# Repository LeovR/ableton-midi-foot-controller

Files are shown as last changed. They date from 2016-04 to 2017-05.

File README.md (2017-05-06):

# AMTraC - Ableton Midi fooT Controller
MIDI foot controller for Ableton

Use in combination with [AMTraC-Info](https://github.com/LeovR/amtrac-info)

## Introduction
For a band project of mine we wanted to extend our sound with samples. Therefore, I needed the possibility to start songs by foot. In addition, I wanted to have the opportunity to stop songs, repeat a part of a song, check the tempo, and see which part the song is currently in.

To add samples to your sound, in a live setup, the software which usually is used is [Ableton Live](http://www.ableton.com).
Ableton Live let's you trigger a lot of things via MIDI, which covers a lot of things I wanted to have.
There are a lot of MIDI foot controllers out there which could be used for such a setup. But none of these covered all my needs for such a controller. Thus, I decided to build my own MIDI controller.

## Hardware

### Controller
For the controller I decided to use the [Teensy 3.2](https://www.pjrc.com/store/teensy32.html) controller which is Arduino compatible, has 34 Digital I/O pins and natively supports MIDI. Thus, it is quite easy to use MIDI.

### Case
For the controller I wanted to have 2 have an LCD, to display the current song / part, 1 stop-Button, 1 play/repeat-Button, 2 bank-switch-buttons and 6 buttons to select a song. Each button should have a corresponding LED and I wanted to have an additional LED which corresponds to the click of the song.
Thus, in total I needed a quite large case to fit everything on it.

After some googling I decided to use the **Hammond 1441-14** case.

I used simple LEDs and foot buttons.

## LCD
As the LCD I used a **Blue IIC 16x2 LCD** which should have enough space to display the required information.

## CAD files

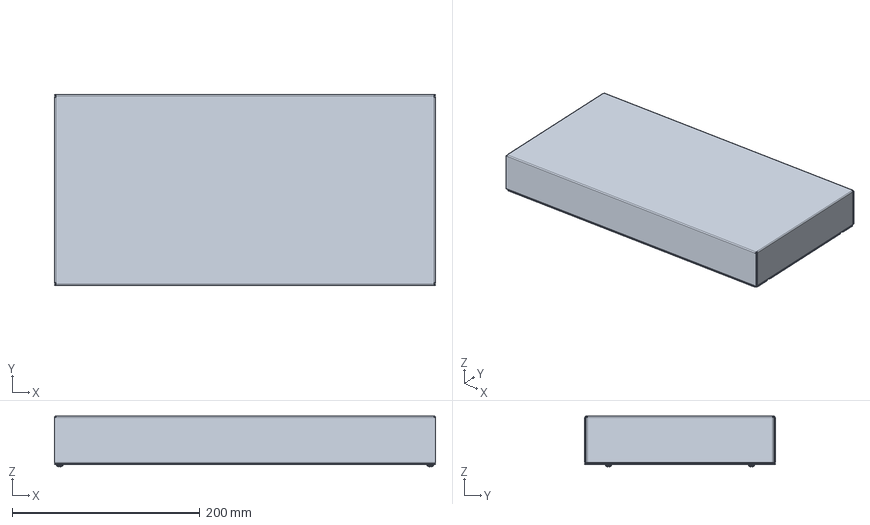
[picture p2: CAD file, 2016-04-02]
gehaeuse.fcstd
406.4 x 203.2 x 54.2 mm
_441_26___Assembly
_441_26___Assembly001
_441_26___Assembly002
_441_26___Assembly003
_441_26___Assembly004
_441_26___Assembly005

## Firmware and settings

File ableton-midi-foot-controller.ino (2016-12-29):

#include "Button.h"
#include "base64/Base64.h"
#include <Wire.h>
#include "NewLiquidCrystal/LiquidCrystal_I2C.h"

//#define DEBUG_BUTTONS true
//#define SINGLE_LED_TEST true
//#define LCD_TEST true
//#define SONG_CONFIGURATION_DEBUG true
//#define DEBUG_BANK true

byte counter;
byte tempCounter;
const byte CLOCK = 248;
const byte START = 250;
const byte CONTINUE = 251;
const byte STOP = 252;

#define SYSEX_BUFFER_SIZE 100
char sysexBuffer[SYSEX_BUFFER_SIZE];

#define MAX_ROW_LENGTH 16

char partBuffer[MAX_ROW_LENGTH + 1];

// LEDs
const byte ledPin = 13;
const byte bpmLed = 17;
const byte ledPins[] = {10, 11, 12, 14, 15, 16};
const byte bankDownLed = 22;
const byte bankUpLed = 23;
const byte playLed = 20;
const byte stopLed = 21;

const byte allLeds[] = {ledPin, bpmLed, ledPins[0], ledPins[1], ledPins[2],
                        ledPins[3], ledPins[4], ledPins[5], bankDownLed, bankUpLed, playLed, stopLed
                       };

const byte numberOfLeds = 12;

// LCD
LiquidCrystal_I2C lcd(0x3F, 2, 1, 0, 4, 5, 6, 7, 3, POSITIVE);

// Buttons
const byte channelButtonStart = 0;
const byte numberOfChannelButtons = 6;
const byte numberOfAllButtons = 10;

const byte bankDownPin = 6;
const byte bankUpPin = 7;

const byte stopPin = 8;
const byte playPin = 9;

Button channelButtons[numberOfChannelButtons];

Button bankDownButton = Button();
Button bankUpButton = Button();
boolean bankDownState;
boolean bankDownDown;
boolean bankUpState;
boolean bankUpDown;

Button stopButton = Button();
Button playButton = Button();
boolean stopState;
boolean stopDown;
boolean playState;
boolean playDown;

Button* allButtons[numberOfChannelButtons + 4];

boolean bankDownLastState = false;
boolean bankUpLastState = false;

byte bank = 0;

const byte numberOfBanks = 5;

const byte numberOfPadBanks = 2;

// Modes
const byte UNCONFIGURED = 0;
const byte NORMAL_MODE = 1;
const byte INIT_MODE = 2;
const byte SONG_MODE = 3;
const byte modeCount = 4;
byte mode = UNCONFIGURED;

byte initBank = 0;

const char mode_0[] PROGMEM = "Normal-Mode";
const char mode_1[] PROGMEM = "Init-Mode";
const char* const modeNames[] PROGMEM = {mode_0, mode_1};

const char displayName[] PROGMEM = "AMTraC";

boolean bothBanksDown = false;

const byte midiChannel = 1;

const byte SONG_CONFIGURATION = 0;
const byte CONFIGURATION_START = 1;
const byte CONFIGURATION_FINISHED = 2;
const byte CURRENT_PART = 3;
const byte NEXT_PART = 4;
const byte SONG_SIGNATURE = 5;
const byte METRONOME = 6;
const byte PAD_CONFIGURATION = 7;

const byte SONG_OFFSET = 10;

const byte numberOfSongs = 30;
char songs[numberOfSongs][MAX_ROW_LENGTH + 1];

const byte CONTROL_OFFSET = SONG_OFFSET + numberOfSongs + 1;

const byte numberOfControls = 10;

const byte STOP_MIDI_NOTE = 0;
const byte REPEAT_MIDI_NOTE = CONTROL_OFFSET;
const byte SEND_CONFIGURATION = CONTROL_OFFSET + 1;
const byte STOP_CLIPS = CONTROL_OFFSET + 2;
const byte METRONOME_MIDI_NOTE = CONTROL_OFFSET + 3;

const byte PAD_OFFSET = CONTROL_OFFSET + numberOfControls + 1;
const byte numberOfPads = 12;
char pads[numberOfPads][MAX_ROW_LENGTH + 1];

byte selectedSong = -1;
byte selectedPad = -1;
const byte INVALID_MIDI_NOTE = 254;
byte midiNoteToSend = INVALID_MIDI_NOTE;
elapsedMillis midiNoteSendStart = 0;
boolean startedMidiNoteSending = false;

boolean playing = false;
byte numerator;
byte denominator;
byte bars;
double fullDenominator;

byte currentNumerator = 0;

boolean nextPartScheduled = false;

boolean repeat = false;
elapsedMillis repeatElapsed = 0;

elapsedMillis triggeredElapsed = 0;
boolean metronomeOn = false;

void OnNoteOn(byte channel, byte note, byte velocity) {
  digitalWrite(ledPin, HIGH);
}

void OnNoteOff(byte channel, byte note, byte velocity) {
  digitalWrite(ledPin, LOW);
}

void SystemExclusiveMessage(const unsigned char *array, short unsigned int size, bool sysexbool) {
  unsigned char *dataArray = (unsigned char*)(array + 4);
  unsigned int realSize = size - 5;

  int decodedLen = base64_dec_len((char*)dataArray, realSize);
  char decoded[decodedLen];

  base64_decode(decoded, (char*)dataArray, realSize);

  boolean isConfigurationMessage = strchr(decoded, '{') != NULL;

  if (isConfigurationMessage) {
    byte configurationType = getConfigurationType(decoded + 1);
    switch (configurationType) {
      case SONG_CONFIGURATION:
        handleSongConfiguration(decoded + 4);
        break;
      case CONFIGURATION_START:
        handleConfigurationStart();
        break;
      case CONFIGURATION_FINISHED:
        handleConfigurationFinished();
        break;
      case CURRENT_PART:
        handleCurrentPart(decoded + 4);
        break;
      case NEXT_PART:
        handleNextPart(decoded + 4);
        break;
      case SONG_SIGNATURE:
        handleSongSignature(decoded + 4);
        break;
      case METRONOME:
        handleMetronome(decoded + 3);
        break;
      case PAD_CONFIGURATION:
        handlePadConfiguration(decoded + 4);
        break;
    }
  }
}

void handleCurrentPart(char* message) {
  if (mode != SONG_MODE) {
    return;
  }

  copyToDisplayBuffer(partBuffer, message);

  nextPartScheduled = false;
  bars = 0;

  lcd.clear();
  lcd.setCursor(0, 0);
  lcd.print(partBuffer);
}

void handleSongSignature(char* messageOriginal) {
  if (mode != SONG_MODE) {
    return;
  }
  sysexBuffer[0] = (char)0;

  strcpy(sysexBuffer, messageOriginal);
  char* strings;
  strings = strtok(sysexBuffer, "|");
  if (strings == NULL) {
    return;
  }

  byte numeratorTemp = atoi(strings);

  strings = strtok(NULL, "|");
  if (strings == NULL) {
    return;
  }

  byte denominatorTemp = atoi(strings);
  numerator = numeratorTemp;
  denominator = denominatorTemp;

}

void clearLine(byte line) {
  lcd.setCursor(0, line);
  lcd.print(F("                "));
}

void handleNextPart(char* message) {
  if (mode != SONG_MODE) {
    return;
  }

  copyToDisplayBuffer(partBuffer, message);

  nextPartScheduled = true;
  triggeredElapsed = 0;

  clearLine(1);
  lcd.setCursor(0, 1);
  lcd.print(partBuffer);
}

void handleMetronome(char* message) {
  metronomeOn = strcmp(message, "1") == 0;
}

void copyToDisplayBuffer(char* displayBuffer, char* message) {
  displayBuffer[0] = (char)0;

  strncpy(displayBuffer, message, MAX_ROW_LENGTH);
  byte messageLength = strlen(message);
  if (messageLength < MAX_ROW_LENGTH) {
    displayBuffer[messageLength] = (char)0;
  } else {
    displayBuffer[MAX_ROW_LENGTH] = (char)0;
  }
}

void handleConfigurationStart() {
  lcd.clear();
  lcd.print(F("Configuration"));
  lcd.setCursor(0, 1);
  lcd.print(F("start"));
}

void handleConfigurationFinished() {
#ifdef SONG_CONFIGURATION_DEBUG
  for (byte i = 0; i < numberOfSongs; i++) {
    if (songs[i]) {
      Serial.print(i);
      Serial.print(F(" "));
      Serial.println(songs[i]);
    }
  }
#endif
  lcd.clear();
  lcd.print(F("Configuration"));
  lcd.setCursor(0, 1);
  lcd.print(F("finished"));

  allLedsTest();
  lcd.clear();

  selectedSong = 0;
  selectedPad = 0;
  changeMode(NORMAL_MODE);
}

void handleSongConfiguration(char* messageOriginal) {
  sysexBuffer[0] = (char)0;
  strcpy(sysexBuffer, messageOriginal);
  char* strings;
  strings = strtok(sysexBuffer, "|");
  if (strings == NULL) {
    return;
  }

  byte index = atoi(strings);

  strings = strtok(NULL, "|");
  if (strings == NULL) {
    return;
  }

#ifdef SONG_CONFIGURATION_DEBUG
  Serial.print(F("Received song configuration "));
  Serial.print(index);
  Serial.print(F(" "));
  Serial.println(strings);
#endif

  copyToDisplayBuffer(songs[index], strings);
}


void handlePadConfiguration(char* messageOriginal) {
  sysexBuffer[0] = (char)0;
  strcpy(sysexBuffer, messageOriginal);
  char* strings;
  strings = strtok(sysexBuffer, "|");
  if (strings == NULL) {
    return;
  }

  byte index = atoi(strings);

  strings = strtok(NULL, "|");
  if (strings == NULL) {
    return;
  }

  copyToDisplayBuffer(pads[index], strings);
}

byte getConfigurationType(char* messageOriginal) {
  strcpy(sysexBuffer, messageOriginal);
  char* strings;
  strings = strtok(sysexBuffer, "|");
  if (strings == NULL) {
    return -1;
  }
  if (strcmp(strings , "SC") == 0) {
    return SONG_CONFIGURATION;
  } else if (strcmp(strings , "CS") == 0) {
    return CONFIGURATION_START;
  } else if (strcmp(strings , "CF") == 0) {
    return CONFIGURATION_FINISHED;
  } else if (strcmp(strings, "CP") == 0) {
    return CURRENT_PART;
  } else if (strcmp(strings, "NP") == 0) {
    return NEXT_PART;
  } else if (strcmp(strings, "SS") == 0) {
    return SONG_SIGNATURE;
  } else if (strcmp(strings, "M") == 0) {
    return METRONOME;
  } else if (strcmp(strings, "PC") == 0) {
    return PAD_CONFIGURATION;
  }
  return -1;
}

void setupButtons() {
  for (byte i = 0; i < numberOfChannelButtons; i++) {
    channelButtons[i].init(channelButtonStart + i, ledPins[i]);
    allButtons[i] = &channelButtons[i];
  }
  bankDownButton.init(bankDownPin, bankDownLed);
  allButtons[numberOfChannelButtons + 0] = &bankDownButton;
  bankUpButton.init(bankUpPin, bankUpLed);
  allButtons[numberOfChannelButtons + 1] = &bankUpButton;
  stopButton.init(stopPin, stopLed);
  allButtons[numberOfChannelButtons + 2] = &stopButton;
  playButton.init(playPin, playLed);
  allButtons[numberOfChannelButtons + 3] = &playButton;
}

void setupLeds() {
  pinMode(ledPin, OUTPUT);
  pinMode(bpmLed, OUTPUT);
}


void setup()
{
  setupButtons();
  setupLeds();

  Serial.begin(9600);

  setupLcd();

  usbMIDI.setHandleNoteOff(OnNoteOff);
  usbMIDI.setHandleNoteOn(OnNoteOn);
  usbMIDI.setHandleRealTimeSystem(RealTimeSystem);
  usbMIDI.setHandleSysEx(SystemExclusiveMessage);

#ifdef LCD_TEST
  lcdTest();
#endif
#ifdef SINGLE_LED_TEST
  ledTest();
#endif

  lcd.clear();
  lcd.setCursor(0, 0);
  lcd.print(displayName);
  allLedsTest();

  delay(3000);

  midiNoteSendStart = 0;
  midiNoteToSend = SEND_CONFIGURATION;
}

#ifdef LCD_TEST
void lcdTest() {
  for (int i = 0; i < 3; i++) {
    lcd.backlight();
    delay(250);
    lcd.noBacklight();
    delay(250);
  }
  lcd.backlight();
}
#endif

void setupLcd() {
  lcd.begin(16, 2);
  lcd.backlight();
}

#ifdef SINGLE_LED_TEST
void ledTest() {
  ledTest(ledPin);
  ledTest(bpmLed);
  for (byte i = 0; i < numberOfChannelButtons; i++) {
    ledTest(ledPins[i]);
  }
  ledTest(bankDownLed);
  ledTest(bankUpLed);
  ledTest(stopLed);
  ledTest(playLed);
}
#endif

void allLedsTest() {
  for (int i = 0; i < numberOfLeds; i++) {
    digitalWrite(allLeds[i], HIGH);
  }
  delay(1000);
  for (int i = 0; i < numberOfLeds; i++) {
    digitalWrite(allLeds[i], LOW);
  }
}

void ledTest(byte pin) {
  digitalWrite(pin, HIGH);
  delay(150);
  digitalWrite(pin, LOW);
  delay(150);
}

void debugButton(Button *button) {
#ifdef DEBUG_BUTTONS
  Serial.print(F("Button: "));
  Serial.print((*button).getPin());
  Serial.print(F(" Just pressed: "));
  Serial.print((*button).isJustPressed());
  Serial.print(F(" Pressed: "));
  Serial.print((*button).isPressed());
  Serial.print(F(" Just released : "));
  Serial.println((*button).isJustReleased());
#endif
}

void updateButtons() {
  for (byte i = 0; i < numberOfAllButtons; i++) {
    if ((*allButtons[i]).update()) {
      debugButton(allButtons[i]);
    }
  }
}

void sendInitMidiNotes() {
  for (byte i = 0; i < numberOfChannelButtons; i++) {
    if (channelButtons[i].isJustReleased()) {
      usbMIDI.sendNoteOff(i + (initBank * numberOfChannelButtons), 0, midiChannel);
    } else if (channelButtons[i].isJustPressed()) {
      usbMIDI.sendNoteOn(i + (initBank * numberOfChannelButtons), 99, midiChannel);
      Serial.print(F("Midi-Note "));
      Serial.println(i + (initBank * numberOfChannelButtons));
    }
  }
}


void sendMidiNote() {
  if (midiNoteToSend != INVALID_MIDI_NOTE) {
    if (midiNoteSendStart > 100) {
      usbMIDI.sendNoteOff(midiNoteToSend, 0, midiChannel);
      midiNoteToSend = INVALID_MIDI_NOTE;
      startedMidiNoteSending = false;
    } else if (!startedMidiNoteSending) {
      usbMIDI.sendNoteOn(midiNoteToSend, 99, midiChannel);
      startedMidiNoteSending = true;
    }
  }
}

void loop()
{
  usbMIDI.read();

  updateButtons();

  boolean modeChange = changeMode();
  if (modeChange) {
    if (mode == NORMAL_MODE && playing) {
      mode = SONG_MODE;
    } else if (mode == SONG_MODE) {
      mode = NORMAL_MODE;
      turnAllChannelButtonsOff();
      resetBankLeds();
      turnCurrentSelectionLedOn();
      printCurrentSelection();
    }
    return;
  }

  if (bothBanksDown) {
    return;
  }

  switch (mode) {
    case NORMAL_MODE:
      handleNormalMode();
      break;
    case INIT_MODE:
      handleInitMode();
      break;
    case SONG_MODE:
      handleSongMode();
      break;
    case UNCONFIGURED:
      handleUnconfigured();
      break;
  }
}

void handleUnconfigured() {
  sendMidiNote();
}

void turnCurrentSelectionLedOn() {
  if (bank < numberOfBanks) {
    turnCurrentSongLedOn();
  } else {
    turnCurrentPadLedOn();
  }
}

void printCurrentSelection() {
  if (bank < numberOfBanks) {
    printCurrentSong();
  } else {
    printCurrentPad();
  }
}

void handleSongMode() {
  if (!repeat) {
    if (playing) {
      playButton.turnLedOn();
    } else {
      playButton.turnLedOff();
    }
  }

  if (metronomeOn) {
    bankDownButton.turnLedOn();
  } else {
    bankDownButton.turnLedOff();
  }

  if (bankDownButton.isJustReleased()) {
    midiNoteSendStart = 0;
    midiNoteToSend = METRONOME_MIDI_NOTE;
  }


  if (stopButton.isJustPressed()) {
    stopButton.turnLedOn();
  }

  if (stopButton.isJustReleased()) {
    midiNoteSendStart = 0;
    midiNoteToSend = STOP_MIDI_NOTE;
    bars = 0;
    nextPartScheduled = false;
    changeMode(NORMAL_MODE);
    return;
  }

  if (playButton.isJustReleased()) {
    repeat = !repeat;
    repeatElapsed = 0;
    midiNoteSendStart = 0;
    midiNoteToSend = REPEAT_MIDI_NOTE;
  }

  if (repeat && repeatElapsed > 300) {
    if (playButton.isLedTurnedOn()) {
      playButton.turnLedOff();
    } else {
      playButton.turnLedOn();
    }
    repeatElapsed = 0;
  }

  if (!nextPartScheduled) {
    bankUpButton.turnLedOff();
  }

  if (triggeredElapsed > 200 && nextPartScheduled) {
    if (bankUpButton.isLedTurnedOn()) {
      bankUpButton.turnLedOff();
    } else {
      bankUpButton.turnLedOn();
    }
    triggeredElapsed = 0;
  }

  sendMidiNote();
}

void changeMode(byte newMode) {
  mode = newMode;
  resetLeds();
  if (mode == NORMAL_MODE) {
    handleNormalMode(true);
  }
}

void handleInitMode() {
  changeInitMidiBank();
  sendInitMidiNotes();
  updateInitLeds();
}

void changeInitMidiBank() {
  boolean update = false;
  if (bankDownButton.isJustReleased()) {
    initBank--;
    if (initBank == 255) {
      initBank = 126;
    }
    update = true;
  } else if (bankUpButton.isJustReleased()) {
    initBank++;
    initBank = initBank % 127;
    update = true;
  }
  if (update) {
    Serial.print(F("MIDI offset "));
    Serial.println(initBank);
  }
}

void handleNormalMode(boolean forceUpdate) {
  boolean bankChange = changeBank();
  if (bankChange) {
    selectedSong = 0;
    selectedPad = 0;
  }
  boolean update = false;
  boolean padUpdate = false;

  boolean songChange = bank < numberOfBanks;

  for (byte i = 0; i < numberOfChannelButtons; i++) {
    if (channelButtons[i].isJustReleased()) {
      if (songChange) {
        update = selectedSong != i;
        selectedSong = i;
      } else {
        padUpdate = selectedPad != i;
        selectedPad = i;
      }
    }
  }

  if (update || (songChange && (forceUpdate || bankChange))) {
    turnAllChannelButtonsOff();
    turnCurrentSongLedOn();
    printCurrentSong();
  }

  if (padUpdate || (!songChange && (forceUpdate || bankChange))) {
    turnAllChannelButtonsOff();
    turnCurrentPadLedOn();
    printCurrentPad();
  }

  if (playButton.isJustPressed()) {
    playButton.turnLedOn();
  }

  if (playButton.isJustReleased()) {
    midiNoteSendStart = 0;
    if (songChange) {
      midiNoteToSend = selectedSong + (bank * numberOfChannelButtons) + SONG_OFFSET;
    } else {
      midiNoteToSend = selectedPad + ((bank - numberOfBanks) * numberOfChannelButtons) + PAD_OFFSET;
    }
    playButton.turnLedOff();
    if (playing) {
      mode = SONG_MODE;
    }
  }

  if (stopButton.isJustPressed()) {
    stopButton.turnLedOn();
  }

  if (stopButton.isJustReleased()) {
    if (midiNoteToSend == INVALID_MIDI_NOTE) {
      midiNoteSendStart = 0;
      if (playing) {
        midiNoteToSend = STOP_MIDI_NOTE;
      } else {
        midiNoteToSend = STOP_CLIPS;
      }
    }
    stopButton.turnLedOff();
  }

  sendMidiNote();
}

void turnCurrentSongLedOn() {
  channelButtons[selectedSong].turnLedOn();
}

void turnCurrentPadLedOn() {
  channelButtons[selectedPad].turnLedOn();
}

void printCurrentSong() {
  char* song = songs[selectedSong + (bank * numberOfChannelButtons)];
  lcd.clear();
  if (song) {
    lcd.print(song);
    lcd.setCursor(0, 1);
    lcd.print(F("Bank: "));
    lcd.print(bank + 1);
    lcd.print(F(" Song: "));
    lcd.print(selectedSong + 1);
  }
}


void printCurrentPad() {
  char* pad = pads[selectedPad + ((bank - numberOfBanks) * numberOfChannelButtons)];
  lcd.clear();
  if (pad) {
    lcd.print(pad);
    lcd.setCursor(0, 1);
    lcd.print(F("Bank: "));
    lcd.print((bank - numberOfBanks) + 1);
    lcd.print(F(" Pad: "));
    lcd.print(selectedPad + 1);
  }
}

void handleNormalMode() {
  handleNormalMode(false);
}

boolean changeMode() {
  if (bankDownButton.isPressed() && bankUpButton.isPressed()) {
    bothBanksDown = true;
  } else if (bothBanksDown && ((bankDownButton.isJustReleased() && !bankUpButton.isPressed()) || (bankUpButton.isJustReleased() && !bankDownButton.isPressed()))) {
    bothBanksDown = false;
    return true;
  } else if (bothBanksDown) {
    return false;
  }
  return false;
}

boolean changeBank() {
  boolean update = false;
  if (bankDownButton.isJustReleased()) {
    bank--;
    update = true;
    if (bank == 255) {
      bank = numberOfBanks + numberOfPadBanks - 1 ;
    }
  } else if (bankUpButton.isJustReleased()) {
    bank++;
    bank = bank % (numberOfBanks + numberOfPadBanks);
    update = true;
  }
#ifdef DEBUG_BANK
  if (update) {
    Serial.print(F("Bank "));
    Serial.println(bank);
  }
#endif
  return update;
}

void updateInitLeds() {
  for (byte i = 0; i < numberOfAllButtons; i++) {
    if ((*allButtons[i]).isPressed()) {
      (*allButtons[i]).turnLedOn();
    } else {
      (*allButtons[i]).turnLedOff();
    }
  }
}

void resetBankLeds() {
  bankUpButton.turnLedOff();
  bankDownButton.turnLedOff();
}

void resetLeds() {
  for (byte i = 0; i < numberOfLeds; i++) {
    digitalWrite(allLeds[i], LOW);
  }
}

void handleBarChange() {
  if (mode != SONG_MODE || nextPartScheduled) {
    return;
  }
  clearLine(1);
  lcd.setCursor(0, 1);
  lcd.print(bars);
  lcd.print(F(" bars"));
}

void turnAllChannelButtonsOff() {
  for (byte i = 0; i < numberOfChannelButtons; i++) {
    channelButtons[i].turnLedOff();
  }
}

void RealTimeSystem(byte realtimebyte) {
  if (realtimebyte == CLOCK) {
    counter++;

    if (denominator > 0) {
      double tempIncrease = (tempCounter / 24.0) * (denominator / 4.0);
      double increase = (1 / 24.0) * (denominator / 4.0) + tempIncrease;
      fullDenominator = fullDenominator + increase;
      tempCounter = 0;

      currentNumerator = ((byte) fullDenominator) % numberOfChannelButtons;

      if (fullDenominator >= numerator && numerator > 0) {
        fullDenominator = 0;
        currentNumerator = 0;
        bars++;
        handleBarChange();
      }
    } else {
      tempCounter++;
    }

    if (counter == 24) {
      counter = 0;
      digitalWrite(bpmLed, HIGH);

      if (mode == SONG_MODE) {
        channelButtons[currentNumerator].turnLedOn();
      }

    }
    if (counter == 5) {
      if (mode == SONG_MODE) {
        turnAllChannelButtonsOff();
      }
      digitalWrite(bpmLed, LOW);
    }
  }

  if (realtimebyte == START || realtimebyte == CONTINUE) {
    counter = 0;
    digitalWrite(bpmLed, HIGH);
  }

  if (realtimebyte == START) {
    playing = true;
    repeat = false;
    fullDenominator = 0;
    currentNumerator = 0;
    changeMode(SONG_MODE);
  }

  if (realtimebyte == STOP) {
    digitalWrite(bpmLed, LOW);
    playing = false;
    bars = 0;
    currentNumerator = 0;
    denominator = 0;
    numerator = 0;
    nextPartScheduled = false;
    changeMode(NORMAL_MODE);
  }
}

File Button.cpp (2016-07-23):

#include "Button.h"

/**
 * Standard-Constructor
 *
 */
Button::Button() {
}

/**
 * Standard-Destructor
 *
 */
Button::~Button() {
}



void Button::init(byte pin, byte led) {
    init(pin);
    pinMode(led, OUTPUT);
    _led = led;
}

void Button::init(byte pin) {
    pinMode(pin, INPUT_PULLUP);
    _button = Bounce();
    _button.attach(pin);
    _button.interval(10);
    _previousState = HIGH;
    _pin = pin;
}

boolean Button::update() {
    boolean change = false;
    if(_justPressed || _justReleased) {
        change = true;
    }
    _justReleased = false;
    _justPressed = false;
    if (_button.update()) {
        byte currentState = _button.read();

        if(currentState != _previousState) {
            if (_pressed && currentState == HIGH) {
                _justReleased = true;
            }
            else if (!_pressed && currentState == LOW) {
                _justPressed = true;
            }
            _pressed = !currentState;
            change = true;
        }

        _previousState = currentState;
    }
    return change;
}

boolean Button::isPressed() {
    return _pressed;
}

boolean Button::isJustPressed() {
    return _justPressed;
}

boolean Button::isJustReleased() {
    return _justReleased;
}

byte Button::getPin() {
    return _pin;
}

void Button::turnLedOn() {
    if(_led) {
        digitalWrite(_led, HIGH);
        _ledOn = true;
    }
}

void Button::turnLedOff() {
    if(_led) {
        digitalWrite(_led, LOW);
        _ledOn = false;
    }
}

boolean Button::isLedTurnedOn() {
  return _ledOn;
}

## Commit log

2016-03-20 Add simple fritzing schematic
    [midicontroller.fzz]
2016-03-20 Add libraries and more buttons
2016-03-20 Improve button intialization and updates
2016-03-20 Add button library
2016-03-20 Update schematic
    [midicontroller.fzz]
2016-03-20 Use new button class
2016-03-20 Put button debug into #ifdef
2016-04-02 Add led methods
2016-04-02 Init buttons with leds
2016-04-02 Added freecad file
    [gehaeuse.fcstd]
2016-04-02 Renamed arduino project file
2016-04-10 Remove imports and disable button debug
2016-04-10 Add all buttons array
2016-04-10 Add reset led function
    [ableton-midi-foot-controller.ino]
2016-04-12 Change midi offsets with bank buttons
2016-07-17 Make led and lcd tests disableable
2016-07-17 Send stop button midi note
2016-07-17 Show current and next part
2016-07-23 Add info whether led is turned on
2016-07-23 Display bars of current part
2016-07-23 Add repeat button functionality (led)
2016-07-23 Correctly reset denominator value
    [ableton-midi-foot-controller.ino]
2016-07-23 Blinking led on triggered part
2016-07-23 Print song number
2016-09-15 Only serial print bank if debug is defined
2016-09-15 Correctly calculate numerator and turn corresponding bank led on
    [ableton-midi-foot-controller.ino]
2016-12-28 Reset schedule status on stop
    [ableton-midi-foot-controller.ino]
